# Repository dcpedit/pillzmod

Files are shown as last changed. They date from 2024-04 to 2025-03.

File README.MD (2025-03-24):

<p align="center">
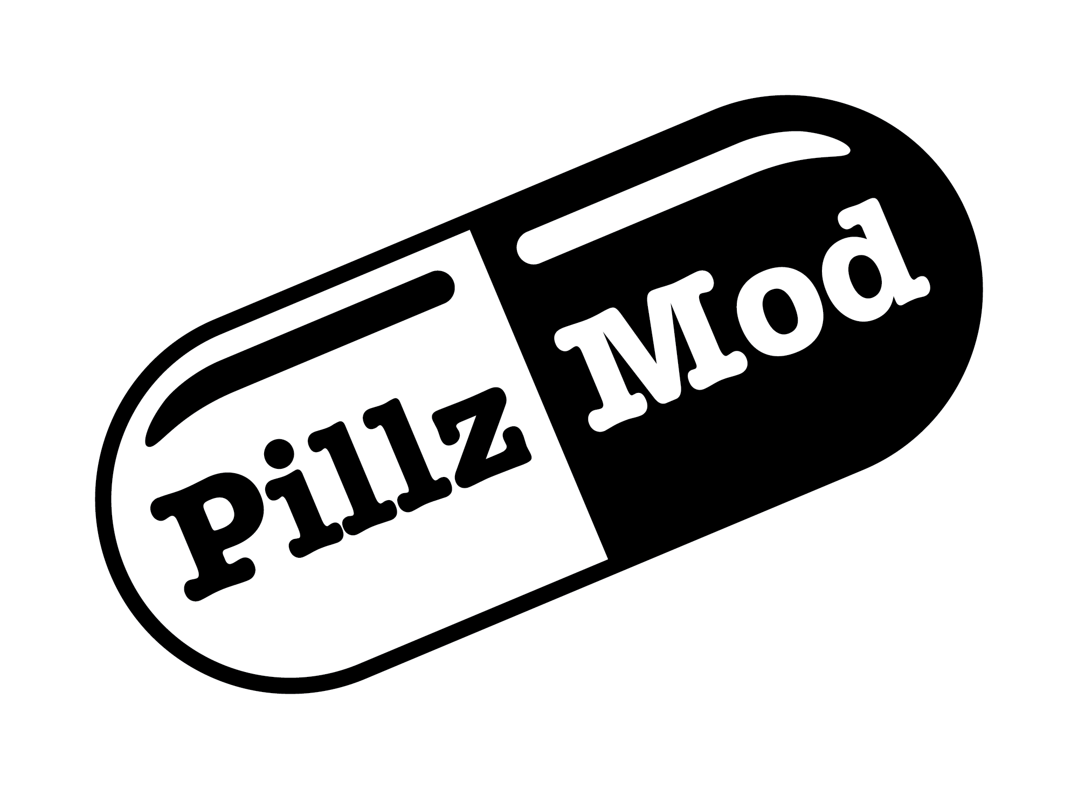
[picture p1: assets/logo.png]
  
</p>

# Pillz Mod for the Kinesis Advantage/Contoured

PCB
PillzMod

This project replaces my two previous forks ([kinesismod](https://github.com/dcpedit/kinesismod) and [kint](https://github.com/dcpedit/kint)) for adding Blackpill support to the Kinesis keyboard.  I've decided to merge all the features into a single PCB, add optional thumb cluster PCBs as part of the kit, and renamed the project to avoid confusion.  Below is a list of supported features.

* Supports Blackpill development board running QMK/Vial
* Supports Pill Bug wireless Bluetooth development board running ZMK
* Optional reversible thumb cluster PCB for left/right sides.  (Maintains original matrix wiring)
* 2u stabilizer support on thumb cluster

## "Pro" PCB Features

* Supports devlopment board with Pro-Micro footprint (Elite-C, Elite-Pi, Nice!Nano)
* Header for connecting up to 3 foot-pedals
* Piezo audio buzzer
* Header for extra data pin (Elite-C only)

## Attribution

Credit goes to the following people for doing all the initial development on replacment PCBs for the Kinesis:
 * Aaron Silman's [kinesismod project](https://gitlab.com/Silman/kinesismod.git) ([blog](https://silman.io/project/kinesis_mod/))
 * Michael Stapelberg's [KinT project](https://github.com/kinx-project/kint) ([blog](https://michael.stapelberg.ch/posts/2020-07-09-kint-kinesis-keyboard-controller/))
 * Dmitry Nosachev's [Kin80 project](https://github.com/DmNosachev/kin80)

## Ordering PCBs from JLCPCB

The files needed for https://jlcpcb.com are located in the production folders:
* Choose `pcb-pro/production` or `pcb/production` 
* `thumb-pcb/production`

Once uploaded, you place the order with the selected default options.  You can optionally change the solder mask color, which changes the final color of your PCB.

## Main PCB build guide
### Components
| Position | Description | Qty | Notes |
| --- | --- | --- | ----- |
| J1-J4 | Molex 39-53-2135 | 2 - 6  | [Link](https://octopart.com/39-53-2135-molex-7670149?r=sp)
| J3-J4 | Molex 39-53-2134 | 0 - 2  | Contoured only, [Link](https://octopart.com/search?q=Molex+39-53-2134)
| U1 | Header pins (1x20) | 2 | Should come with dev board
| U1 | Headers (1x20) | 2 | To socket your dev board
| D1-D4 | 1.8mm LED | 4 | [Amazon](https://a.co/d/90uynIs)
| R1-R4 | 10k resistor | 4 | Affects LED brightness. Smaller = brighter |
| | USB-C panel mount | 1 | [AliExpress](https://www.aliexpress.us/item/3256806463941289.html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), [Amazon](https://a.co/d/cRoqHqx)

### Blackpill Components
| Position | Description | Qty | Notes |
| --- | --- | --- | ----- |
| U1 | Blackpill (STM32F411) | 1 | [WeAct Store](https://www.aliexpress.com/store/1101545918?spm=a2g0o.order_list.order_list_main.2.18a31802pDYB6d)

#### -or- Pill Bug for wireless build

| Description | Qty | Notes |
| --- | --- | ----- |
| Pill Bug | 1 | [MechWild Store](https://mechwild.com/product/pillbug/)
| 3.7V battery | 1 | [2000mAh](https://a.co/d/dVUdHxi)
| Power button | 1 | Optional, [10mm](https://a.co/d/i33uBM0) or [19mm](https://a.co/d/fYN6ZX5)

### Additional "Pro" Components

| Position | Description | Qty | Notes |
| --- | --- | --- | ----- |
| U1 | Elite-C/Elite-Pi | 1 |
| | 3.7V battery | 1 | [2000mAh](https://a.co/d/dVUdHxi)
| U2 | 74HC595 | 1 | [Amazon](https://a.co/d/eLX9kOY)
| U2 | 16-pin IC socket | 1 | [Amazon](https://a.co/d/5EaFAHo)
| D6-D8 | 1n4148 Diode | 3 | [Link](https://www.mouser.com/ProductDetail/512-1N4148TR)
| BZ1 | Piezo Buzzer | 1 | [Link](https://www.digikey.com/en/products/detail/tdk-corporation/PS1240P02BT/935924)
| SW1 | Reset button | 1 | [Link](https://www2.mouser.com/ProductDetail/Alps-Alpine/SKQGAEE010?qs=N5Jky1br14PyTRvcw7F3eQ%3D%3D)
| R5-R19 | 10k Resistor | 15| AVR/Elite-C Only [Link](https://www.mouser.com/ProductDetail/YAGEO/MFR-12FTF52-10K?qs=oAGoVhmvjhzLlUYKKBtdYQ%3D%3D), [Link](https://mou.sr/3xgqcNf)

#### -or- Nice!Nano for wireless build

| Description | Qty | Notes |
| --- | --- | ----- |
| Nice!Nano | 1 | [Website](https://nicekeyboards.com/nice-nano/)
| 3.7V battery | 1 | [2000mAh](https://a.co/d/dVUdHxi)
| Power button | 1 | Optional, [10mm](https://a.co/d/i33uBM0) or [19mm](https://a.co/d/fYN6ZX5)

### Instructions



_NOTE: If you're using a battery that's larger than 500mAh, then bridge the charge boost jumper labeled JP1 with some solder.  This will increases the max charge rate from 100mA to 500mA. Doing this for small batteries (<500mAh) may cause explosions._

All components go on the side with the silkscreen labels (rectangles) EXCEPT for the LEDs.  First solder the header pins onto your development board, and the header sockets onto the PCB.  I prefer to use Mill-Max 310 series sockets because the pins are thin.  Then solder in the LED resistors, but NOT the actual LEDs yet.  The resistors can be SMD or through hole.

For a wireless build, you can now solder the battery wires/connector to the board.  Make sure the positive wire goes into "BAT+", and the negative wire goes into "BAT-".  If you're using a power button, make sure to wire it inline along the BAT+ wire so that it essentially opens and closes the circuit.

Insert your development board into the sockets on the PCB.

For the Molex connectors, I find that it's more convient to desolder the ones on the original PCB so that I don't have to purchase new ones.  Solder the connectors onto the PCB.

Flip the PCB over and insert the LEDs on the side of the PCB with no other components.  Make sure the short leg goes into the square pad, and bend the legs so that they stay in place.  Screw the PCB back into the keyboard case, making sure the LEDs are lined up with the existing case holes.  You can also adjust the height of the LED to move them closer to the status window if you'd like.  Once you're satisfied with the position of the LEDs, you can then solder them in place while the PCB is still mounted.

Lastly, plug the USB-C panel mount cable to into the development board, and secure the other end to the hole in the case.





### "Pro" Additional Instructions

The components required for this build and their position will depend on the development board you're using.  For example, pull-down resistors R5-R19 are only needed for AVR chips (Pro-Micro, Elite-C) since they don't support internal pull-downs for the row inputs.  Use the image below as a guide.



The Elite-C has an extra B0 pin that is broken out into the J10 pins.  You can use this to drive other components if you choose (ie. RGB strip, Solenoid)

* Pin 1 (square pad) - VCC
* Pin 2 - B0
* Pin 3 - GND

The J9 pins are for foot pedals and have the following assignment:

* Pin 1 (square pad) - Col6
* Pin 2 - Row0
* Pin 3 - Row1
* Pin 4 - Row2

Diodes D6-D8 are connected to the rows, so no additional diodes are needed in the pedals/switches.



### "Pro" Nice!Nano Additional Instructions

Mill-Max 310 sockets are recommended for socketing the Nice!Nano because thin pins are required for connecting the extra 3 pins in the middle.

The Nice!Nano is one pin short of supporting all 4 status lights on the Advantage.  If you want to utilize the unused numpad status LED as a power indicator, go ahead and short JP1 with some solder.



## Thumb cluster PCB build guide

The wiring for the thumb cluster (a.k.a. matrix wiring) has not been altered from original, so theoretically, they can be used in conjunction with any Kinesis PCB, including the stock one.

The PCB is also reversible, so you don't have to place separate orders for a "left" version and a "right" version.

### Components

| Description | Qty | Notes |
| --- | --- | ----- |
| 1N4148 SOD-123 diode | 12 | [Amazon](https://a.co/d/gsv8bGT)
| MX switch | 12 | Can desolder and reuse
| 2u screw-in stabilizer | 4 | [Link](https://divinikey.com/products/durock-v2-stabilizers-screw-in)
| Cable connector (1x10) | 4 | 2.54mm pitch (eg KF2510)
| Ribbon cable | 2 | >= 50mm length

### Instructions



You will need two PCBs for the thumb cluster, but since they're reversible, you will need to read the silkscreen to see if it's the left or right cluster.

First step is to solder all the 1N4148 diodes.  Orientation matters, so make sure the line on the diode faces same direction as the thicker white line on the PCB.  Place a dab of solder on ONE of the two diode pads.  Drop the diode into position (double checking the orientation), hold the diode in place with tweezers, and melt the solder you just added to the pad so that diode is held in place.  Now add solder to the opposite pad, thus holding the other diode leg in place.  Repeat for all the other diodes.

The connector for the ribbon cable can now be soldered onto the PCB, and will be on the same side as the diodes.  The pin pitch is 2.54mm, so any compatible connector/cable will work here.

Install the 2u stabilizers onto the PCB.

Now solder in your MX switches.  If you're reusing the original switches, desolder them from the original PCB, and remove the diode from inside the switch housing.  Using a switch opener will make this task much easier.



Mount the thumb clusters onto the keyboard and connect the ribbon cables.



## QMK firmware for "Pro"

* `firmware/pro_qmk_avr_default.bin`
* `firmware/pro_qmk_rp2040_default.uf2`

QMK source: https://github.com/dcpedit/qmk_firmware/tree/pillzmod/keyboards/dcpedit/pillzmod

## Vial firmware for Blackpill

* `firmware/blackpill_vial.bin`
* `firmware/dcpedit_kint_bp_vial_6layers.bin`

Source: https://github.com/dcpedit/vial-qmk/tree/pillzmod/keyboards/dcpedit/pillzmod

Remap keys: https://vial.rocks/

### Flashing firmware under Linux
The file firmware/dcpedit_kint_bp_vial_6layers.bin (or other) can simply be flashed to the Blackpill using the dfu-util. The dfu-util tool requires root privileges if settings are not accessible by the user.

Connect Blackpill to your Linux PC via USB C cable and start unit in DFU mode by holding bootp button and pressing reset button. Wait a second and release the bootp button.

Check the DFU devices by running
```
dfu-util -l
```
The Blackpill device should be visible.

Write the firmware to the device with
```
dfu-util -d 0483:df11 -a 0 -s 0x08000000 -D [PATH TO kint]/firmware/dcpedit_kint_bp_vial_6layers.bin
```

## Vial firmware for "Pro"

* `firmware/pro_vial_avr.hex`

Source: https://github.com/dcpedit/vial-qmk/tree/pillzmod/keyboards/dcpedit/pillzmod
(You will need to clone the entire branch since I had to make a core code change in `spi_master.c`)

## ZMK firmware for Pill Bug



* `firmware/zmk_default.uf2` - Default keymap
* `firmware/zmk_custom.uf2` - Support for up to 6 layers
* `firmware/zmk_reset.uf2` - Resets PillBug board for BT connectivity issue on MacOS      
* `firmware/zmk_studio.uf2` - Studio compatible (Progrm + Esc to unlock)

Source: https://github.com/dcpedit/zmk/tree/pillzmod/app/boards/shields/pillzmod

### Bluetooth with ZMK

The ZMK firmware has mappings for performing system tasks. By default there are 4 Bluetooth pairings saved to the keyboard but they do not switch automatically when adding new devices. So after you add the first device, you need to tell they keyboard to use Bluetooth slot 2 and so forth.
The keys to switch between are accessed by a different keyboard layer. This layer is opened by holding down the "Program" key at the very top right of the Kinesis and, while holding it, then clicking another key as follows:

* **Clear all saved Bluetooth profiles:** Program + F9
* **Bluetooth profile 1:** Program + F1
* **Bluetooth profile 2:** Program + F2
* **Bluetooth profile 3:** Program + F3
* **Bluetooth profile 4:** Program + F4
* **Enter bootloader mode (to upload UF2 files):** Program + - (the dash key just below program)

If you want to do a ZMK firmware build using GitHub actions, take a look at the following repository from keepitsimplejim:

https://github.com/keepitsimplejim/zmk-config-pillzmod-kinesis-adv

## ZMK firmware for "Pro" Nice!Nano

* `firmware/pro_zmk.uf2` - Default keymap
* `firmware/pro_zmk_studio.uf2` - Studio compatible (Progrm + Esc to unlock)

Source: https://github.com/dcpedit/zmk/tree/pillzmod/app/boards/shields/pillzmod_pro
Studio: https://zmk.studio/

## KiCad

All the PCBs were designed using KiCad, which is free and can be downloaded here: https://www.kicad.org/

For the thumb cluster PCB, I wasn't able to figure out how to have the left and right wiring co-exist without errors while sharing the same connector footprint.  My workaround was to first change the connector's reference designator to "J1", update the PCB from schematic, and wire up the left side.  Then I changed the reference designator to "J2", updated the PCB from schematic again, and wired up the right side.

If there are any KiCad experts out there that know of a more elegant solution, please let me know.

The production JLCPCB files are all generated with Fabrication Toolkit: https://github.com/bennymeg/Fabrication-Toolkit

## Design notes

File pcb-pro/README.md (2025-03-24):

# Pillz Mod Pro main PCB




Next image shows the mapping of keys to connectors and rows/columns:



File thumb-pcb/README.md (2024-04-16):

# Pillz Mod thumb cluster PCB



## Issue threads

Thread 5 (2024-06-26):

Documentation for flashing

epichub, 2024-06-26:
I am having a hard time figuring out how to flash the qmk .bin file - tried stm32cubeprogrammer, no luck. Trying with qmk compile now.
Would be nice with some docs on how to do it.

epichub, 2024-07-01:
got it to work via https://github.com/dcpedit/vial-qmk/tree/pillzmod/keyboards/dcpedit/pillzmod and
`make dcpedit/pillzmod/standard:default:flash`

but that image does not show up in vial/via - in macos i get "wrong version". maybe the jsons needs a small update?

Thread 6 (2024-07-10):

Blackpill STM32F411 not recognized

skamelone, 2024-07-10:
I'm having trouble flashing this board. Today, I received the **STM32F411** board and decided to check if I could flash it before soldering it onto the PCB. I can successfully flash it, but the board isn't recognized at all in VIA or Vial. I used the firmware [dcpedit_kint_bp_vial_6layers.bin](https://github.com/dcpedit/pillzmod/blob/main/firmware/dcpedit_kint_bp_vial_6layers.bin)

```
vial-qmk ➤ dfu-util --list
dfu-util 0.11

Copyright 2005-2009 Weston Schmidt, Harald Welte and OpenMoko Inc.
Copyright 2010-2021 Tormod Volden and Stefan Schmidt
This program is Free Software and has ABSOLUTELY NO WARRANTY
Please report bugs to http://sourceforge.net/p/dfu-util/tickets/

Found DFU: [0483:df11] ver=2200, devnum=1, cfg=1, intf=0, path="0-1", alt=3, name="@Device Feature/0xFFFF0000/01*004 e", serial="369A388B3233"
Found DFU: [0483:df11] ver=2200, devnum=1, cfg=1, intf=0, path="0-1", alt=2, name="@OTP Memory /0x1FFF7800/01*512 e,01*016 e", serial="369A388B3233"
Found DFU: [0483:df11] ver=2200, devnum=1, cfg=1, intf=0, path="0-1", alt=1, name="@Option Bytes  /0x1FFFC000/01*016 e", serial="369A388B3233"
Found DFU: [0483:df11] ver=2200, devnum=1, cfg=1, intf=0, path="0-1", alt=0, name="@Internal Flash  /0x08000000/04*016Kg,01*064Kg,03*128Kg", serial="369A388B3233"

vial-qmk ➤ dfu-util -vd 0483:df11 -a 0 -s 0x8000000 -D dcpedit_kint_bp_vial_6layers.bin
...
 Download from image offset 00010800 to memory 08010800-08010fff, size 2048
 Download from image offset 00011000 to memory 08011000-080117ff, size 2048
 Download from image offset 00011800 to memory 08011800-08011baf, size 944
File downloaded successfully
```

After reconnecting the board, I start VIA or VIAL and nothing. I also tried another STM32F411 and same thing. Any idea?

skamelone, 2024-07-10:
For anyone having the same error:

- If your board is **F411 8M HSE** (8Mhz) you need to add this to your keymap's rules.mk
```
BOARD = GENERIC_STM32_F411XE
MCU = STM32F411
```

- If your board is **F411 25M HSE** (25Mhz) you need to add this to your keymap's rules.mk
```
BOARD = BLACKPILL_STM32_F411
MCU = STM32F411
```

Closed 2024-07-10.

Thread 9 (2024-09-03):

Alternative for Pill Bug

Sinled, 2024-09-03:
It seems mechwild not accepting order anymore, so is there any alternatives for Pill Bug board, that will be wireless and run zmk?

a10kiloham, 2024-11-09:
the pro @dcpedit released is the answer now.

Closed 2024-11-09.

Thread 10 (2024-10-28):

QMK (Vial) source code pointing to wrong location

dhruvinsh, 2024-10-28:
Hi @dcpedit
As mentioned, the QMK firmware source code is missing. If you can point me to correct location that would be great. :)

dhruvinsh, 2024-10-29:
I think I found it, it was on different branch.
https://github.com/vial-kb/vial-qmk/compare/vial...dcpedit:vial-qmk:pillzmod

if that is the case, document (README.md) file need an update :)

dcpedit, 2024-10-30:
Thanks for pointing that out. Readme updated

Closed 2024-10-30.

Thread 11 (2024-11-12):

Proposal: usage of QH pin from Shift Registers for keypad led

dhruvinsh, 2024-11-12:
Hi.

Is it possible to connect keypad led to shift register pin `QH` ? if not how about moving one of the row to the Shift Register and connect keypad led to the controller?

dcpedit, 2025-01-16:
I considered this as well, but it won't work because the `Q` pins on the 74HC595 are input pins which are connected to the columns (output on MCU).  In order to drive the LED, I would need an output pin.  This is also why I can't use the shift register for row pins (row = input on MCU)

Closed 2025-01-16.

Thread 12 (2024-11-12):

Register Shifter connected on low frequency pin in case of Nice!Nano

dhruvinsh, 2024-11-12:
Register Shifter is connecto to the pin 13, 14 and 16. but in case of nice!nano those are low frequency pin. ZMK recommands to use high frequency pins which are highlighted in dark blue color.

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

HeavyDutySoul, 2024-11-12:
Anybody assemble on n!n? It work?

asmodeus812, 2024-12-28:
> Anybody assemble on n!n? It work?

@HeavyDutySoul have been using the nice nano v2 with the pro pcb version for a few weeks, seems to be working just fine,

dcpedit, 2025-01-16:
@dhruvinsh , thanks for pointing this out.  I chose those pins because they matched up with the SPI pins for the Pro Micro.  Do you know if using the low-freq pins have any adverse effects on the shift register functionality?  It seems to be working fine so far in my build.

dcpedit, 2025-03-24:
Thanks for finding this info. I’ll need to create a separate Nice!Nano-compatible PCB so I can reroute the traces to use the high-frequency pins. I can’t modify the existing PCB without breaking compatibility with the Pro Micro, whose SPI pins can’t be moved.

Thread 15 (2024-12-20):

[Nice Nano - ZMK] Keys on one side register themselves and keys on the other side

asmodeus812, 2024-12-20:
Hello, on the zmk nice nano firmware (latest) from this branch, the column of the 4,r,f,v, registers the keys of that column along side the column on the other side where the 6,y,h,n keys are, (note that the bottom most row works, and the arrow keys are registered correctly on the side they are pressed on) i can also see the same behavior on the thumb cluster where the delete key from the left side registers delete along side the page down on the right, and vice versa if you press page down on the right side it will also register the delete on the other side. I guess this is an issue with the shift register configuration possibly ?

asmodeus812, 2024-12-21:
That was a user error, during the soldering i seem to have used poor quality flux, which had completely covered the board in micro soldering droplets, which were almost impossible to notice, after a cleaning with alchohol the board works as expected, so does the default firmware as well. This is a word of caution for people which might encounter issues with the board while testing, make sure that there are no shorts anywhere.

Closed 2024-12-21.

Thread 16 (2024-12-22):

Do you have pro version of the pcb for sale?

cedounet, 2024-12-22:
Hello

I am not sure  where else to ask.. so using issue for that.

Bare pcb and maybe the hard to find connectors if needed, I am happy to buy them from you (I am in the UK).  If you don’t no issue either just close it.

thanks

ced
Ps: thanks a lot for this high quality work.

Closed 2025-01-03.

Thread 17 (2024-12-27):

Optional through-hole diodes on thumb PCB (feature request)

rwaldura, 2024-12-27:
Hello! Great project, super useful to bring back to life some older keyboards — my 1999 "Classic" thanks you!
I really appreciate how you provided the option to use either SMD or through-hole components for the main PCB, e.g. the LED resistors.
Would it be possible to achieve the same, with the thumb PCB? It appears only SMD is supported at this time.
I'd like to have the option to wire through-hole diodes, rather than SMD diodes, on the thumb PCB.
Thanks!

dcpedit, 2025-01-16:
This will not be difficult since the "left hand" diodes are wired differently than the "right hand" diodes.  In order to do this, I will need to use two diode footprints per key position, or simply just create 2 separate PCBs (one for left and another for right).

rwaldura, 2025-01-16:
I see. This had not occurred to me.
Thank you for looking into it!

rwaldura, 2025-03-24:
Sorry, the resolution here is that this feature will not be supported? Just want to know, thanks!

Closed 2025-03-24.

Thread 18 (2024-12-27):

Optional Molex connectors for thumb PCB (feature request)

rwaldura, 2024-12-27:
Recent Kinesis keyboards (Advantage2, KB600) use flat cables and Molex connectors to connect the main PCB to the thumbs. (Photo attached below.)
The current design requires a different kind of connector (which I don't have — I only got the Molex 39-53-2134 and 39-53-2135, prescribed for this build).
Looks like the main PCB already supports a Molex connector in this position? So this is my request to extend same to the thumb clusters.
Keep up the great work! Thanks!

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

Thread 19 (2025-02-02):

Triggering key and next in column on first rows

cedounet, 2025-02-02:
Hello,

I built the pro-version and used https://keeb.supply/products/0xcb-helios as a controller which is pin compatible to the pro... Everything works fine (on what I tested at least) but the first two rows.

I am using rows/col as per the schematics... so opposite of what it is physically on the keyboard

- Pressing one key on this row will systematically trigger the key _and_ the one below (next column)
   - _= _toggles _=_ and _tab_, tab toggle _tab_ and _capslock_
   - _1_ toggles _1_ and _q_ etc
   - It does that for those 3 first rows

- Same for the end key on thumb cluster that will also trigger a c after it (I reused the original thumb cluster)

I first thought this would be a soldering issue, but:
- I am having a hard time to see where a short would create this... would be all keys i.e. 1,q,a,z, not just the next one
- I have 2 keyboards... 2 controllers and both have the same issue on same rows...
- Using tweezers to activate the switch works flawlessly no triggering of next key.

Base are contour keyboards (PS2, and AT...) if that is relevant and I had some issues with them but not that one as far as i can remember and definitely not that systematic.

Any ideas on what could cause it or how I could debug that?

Thanks!

C

cedounet, 2025-02-05:
Looks like I need to use external pull down resistors… O had understood the RP2040 had internal ones but maybe they are not strong enough.  I only tried quickly but if confirmed I will close that issue…

Thanks

cedounet, 2025-02-22:
Works with pull down…

dcpedit, 2025-02-23:
This is interesting because I tested this with an Elite Pi which also uses an rp2040 and the internal pull downs were sufficient. Maybe I'll make a note of this in the readme.

cedounet, 2025-02-23:
Most key works… just those 2/3 rows.  As I said earlier I somewhat dismiss soldering issues as it happens on 4 combination of PcB and left key wells.

I could clearly see the 2 line going down briefly on the scope etc… and have half baked theories about why… but an extra pulldown sorted it.

I wanted to add the Helios or the readme but not sure if that is the reason it behaves differently from Elite-pi?

Closed 2025-02-22.

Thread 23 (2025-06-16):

zmk-pillzmod-pro does not compile?

epichub, 2025-06-16:
I cannot get you zmk-pillzmod-pro fork to compile.
It fails with some strange error originating from "leds.c" (a file which i cannot find in any other example of in any other board/shield in zmk):

```
[107/342] Building C object CMakeFiles/app.dir/boards/shields/pillzmod_pro/leds.c.obj
In file included from <MYBUILDDIR>/src/zmk-pillzmod/zephyr/include/zephyr/device.h:13,
                 from <MYBUILDDIR>/src/zmk-pillzmod/app/boards/shields/pillzmod_pro/leds.c:1:
<MYBUILDDIR>/src/zmk-pillzmod/zephyr/include/zephyr/init.h:193:44: warning: initialization of 'int (*)(void)' from incompatible pointer type 'int (*)(const struct device *)' [-Wincompatible-pointer-types]
  193 |                         .init_fn = {.sys = (init_fn_)},                        \
      |                                            ^
<MYBUILDDIR>/src/zmk-pillzmod/zephyr/include/zephyr/init.h:174:9: note: in expansion of macro 'SYS_INIT_NAMED'
  174 |         SYS_INIT_NAMED(init_fn, init_fn, level, prio)
      |         ^~~~~~~~~~~~~~
<MYBUILDDIR>/src/zmk-pillzmod/app/boards/shields/pillzmod_pro/leds.c:53:1: note: in expansion of macro 'SYS_INIT'
   53 | SYS_INIT(leds_init, APPLICATION, CONFIG_APPLICATION_INIT_PRIORITY);
      | ^~~~~~~~
<MYBUILDDIR>/src/zmk-pillzmod/zephyr/include/zephyr/init.h:193:44: note: (near initialization for '__init_leds_init.init_fn.sys')
  193 |                         .init_fn = {.sys = (init_fn_)},                        \
      |                                            ^
<MYBUILDDIR>/src/zmk-pillzmod/zephyr/include/zephyr/init.h:174:9: note: in expansion of macro 'SYS_INIT_NAMED'
  174 |         SYS_INIT_NAMED(init_fn, init_fn, level, prio)
      |         ^~~~~~~~~~~~~~
<MYBUILDDIR>/src/zmk-pillzmod/app/boards/shields/pillzmod_pro/leds.c:53:1: note: in expansion of macro 'SYS_INIT'
   53 | SYS_INIT(leds_init, APPLICATION, CONFIG_APPLICATION_INIT_PRIORITY);
      | ^~~~~~~~
[170/342] Building C object CMakeFiles/app.dir/src/studio/behavior_subsystem.c.obj
<MYBUILDDIR>/src/zmk-pillzmod/app/src/studio/behavior_subsystem.c: In function 'encode_value_description':
<MYBUILDDIR>/src/zmk-pillzmod/app/src/studio/behavior_subsystem.c:87:23: warning: assignment discards 'const' qualifier from pointer target type [-Wdiscarded-qualifiers]
   87 |         desc.name.arg = val;
      |                       ^
[175/342] Building C object CMakeFiles/app.dir/src/studio/uart_rpc_transport.c.obj
FAILED: CMakeFiles/app.dir/src/studio/uart_rpc_transport.c.obj
ccache /opt/zephyr-sdk/arm-zephyr-eabi/bin/arm-zephyr-eabi-gcc -DKERNEL -DNRF52840_XXAA -DPB_MAX_REQUIRED_FIELDS=64 -DPB_NO_ENCODE_SIZE_CHECK -DPB_NO_ERRMSG -DPB_WITHOUT_64BIT -DPICOLIBC_INTEGER_PRINTF_SCANF -D_FORTIFY_SOURCE=1 -D_POSIX_C_SOURCE=200809 -D__LINUX_ERRNO_EXTENSIONS__ -D__PROGRAM_START -D__ZEPHYR__=1 -I<MYBUILDDIR>/src/zmk-pillzmod/app/include -I<MYBUILDDIR>/src/zmk-pillzmod/app/build -I<MYBUILDDIR>/src/zmk-pillzmod/zephyr/include -I<MYBUILDDIR>/src/zmk-pillzmod/app/build/zephyr/include/generated -I<MYBUILDDIR>/src/zmk-pillzmod/zephyr/soc/arm/nordic_nrf/nrf52 -I<MYBUILDDIR>/src/zmk-pillzmod/zephyr/soc/arm/nordic_nrf/common/. -I<MYBUILDDIR>/src/zmk-pillzmod/zephyr/subsys/usb/device -I<MYBUILDDIR>/src/zmk-pillzmod/zephyr/subsys/bluetooth/controller/ll_sw/nordic/hal/nrf5/nrfx_glue -I<MYBUILDDIR>/src/zmk-pillzmod/zephyr/subsys/bluetooth -I<MYBUILDDIR>/src/zmk-pillzmod/zephyr/subsys/settings/include -I<MYBUILDDIR>/src/zmk-pillzmod/modules/lib/nanopb -I<MYBUILDDIR>/src/zmk-pillzmod/modules/hal/cmsis/CMSIS/Core/Include -I<MYBUILDDIR>/src/zmk-pillzmod/zephyr/modules/cmsis/. -I<MYBUILDDIR>/src/zmk-pillzmod/modules/hal/nordic/nrfx -I<MYBUILDDIR>/src/zmk-pillzmod/modules/hal/nordic/nrfx/drivers/include -I<MYBUILDDIR>/src/zmk-pillzmod/modules/hal/nordic/nrfx/mdk -I<MYBUILDDIR>/src/zmk-pillzmod/zephyr/modules/hal_nordic/nrfx/. -I<MYBUILDDIR>/src/zmk-pillzmod/modules/crypto/tinycrypt/lib/include -I<MYBUILDDIR>/src/zmk-pillzmod/app/module/include -I<MYBUILDDIR>/src/zmk-pillzmod/app/module/drivers/sensor/battery/. -fno-strict-aliasing -Os -imacros <MYBUILDDIR>/src/zmk-pillzmod/app/build/zephyr/include/generated/autoconf.h -fno-printf-return-value -fno-common -g -gdwarf-4 -fdiagnostics-color=always -mcpu=cortex-m4 -mthumb -mabi=aapcs -mfpu=fpv4-sp-d16 -mfloat-abi=hard -mfp16-format=ieee --sysroot=/opt/zephyr-sdk/arm-zephyr-eabi/arm-zephyr-eabi -imacros <MYBUILDDIR>/src/zmk-pillzmod/zephyr/include/zephyr/toolchain/zephyr_stdint.h -Wall -Wformat -Wformat-security -Wno-format-zero-length -Wno-pointer-sign -Wpointer-arith -Wexpansion-to-defined -Wno-unused-but-set-variable -Werror=implicit-int -fno-pic -fno-pie -fno-asynchronous-unwind-tables -ftls-model=local-exec -fno-reorder-functions --param=min-pagesize=0 -fno-defer-pop -fmacro-prefix-map=<MYBUILDDIR>/src/zmk-pillzmod/app=CMAKE_SOURCE_DIR -fmacro-prefix-map=<MYBUILDDIR>/src/zmk-pillzmod/zephyr=ZEPHYR_BASE -fmacro-prefix-map=<MYBUILDDIR>/src/zmk-pillzmod=WEST_TOPDIR -ffunction-sections -fdata-sections --specs=picolibc.specs -std=c99 -Wfatal-errors -MD -MT CMakeFiles/app.dir/src/studio/uart_rpc_transport.c.obj -MF CMakeFiles/app.dir/src/studio/uart_rpc_transport.c.obj.d -o CMakeFiles/app.dir/src/studio/uart_rpc_transport.c.obj -c <MYBUILDDIR>/src/zmk-pillzmod/app/src/studio/uart_rpc_transport.c
In file included from <MYBUILDDIR>/src/zmk-pillzmod/zephyr/include/zephyr/toolchain/gcc.h:98,
                 from <MYBUILDDIR>/src/zmk-pillzmod/zephyr/include/zephyr/toolchain.h:50,
                 from <MYBUILDDIR>/src/zmk-pillzmod/zephyr/include/zephyr/sys/util.h:18,
                 from <MYBUILDDIR>/src/zmk-pillzmod/zephyr/include/zephyr/init.h:13,
                 from <MYBUILDDIR>/src/zmk-pillzmod/app/src/studio/uart_rpc_transport.c:7:
<MYBUILDDIR>/src/zmk-pillzmod/zephyr/include/zephyr/device.h:85:41: error: '__device_dts_ord_DT_CHOSEN_zmk_studio_rpc_uart_ORD' undeclared here (not in a function)
   85 | #define DEVICE_NAME_GET(dev_id) _CONCAT(__device_, dev_id)
      |                                         ^~~~~~~~~
<MYBUILDDIR>/src/zmk-pillzmod/zephyr/include/zephyr/toolchain/common.h:137:26: note: in definition of macro '_DO_CONCAT'
  137 | #define _DO_CONCAT(x, y) x ## y
      |                          ^
<MYBUILDDIR>/src/zmk-pillzmod/zephyr/include/zephyr/device.h:85:33: note: in expansion of macro '_CONCAT'
   85 | #define DEVICE_NAME_GET(dev_id) _CONCAT(__device_, dev_id)
      |                                 ^~~~~~~
<MYBUILDDIR>/src/zmk-pillzmod/zephyr/include/zephyr/device.h:212:37: note: in expansion of macro 'DEVICE_NAME_GET'
  212 | #define DEVICE_DT_NAME_GET(node_id) DEVICE_NAME_GET(Z_DEVICE_DT_DEV_ID(node_id))
      |                                     ^~~~~~~~~~~~~~~
<MYBUILDDIR>/src/zmk-pillzmod/zephyr/include/zephyr/device.h:229:34: note: in expansion of macro 'DEVICE_DT_NAME_GET'
  229 | #define DEVICE_DT_GET(node_id) (&DEVICE_DT_NAME_GET(node_id))
      |                                  ^~~~~~~~~~~~~~~~~~
<MYBUILDDIR>/src/zmk-pillzmod/app/src/studio/uart_rpc_transport.c:21:46: note: in expansion of macro 'DEVICE_DT_GET'
   21 | static const struct device *const uart_dev = DEVICE_DT_GET(UART_DEVICE_NODE);
      |                                              ^~~~~~~~~~~~~
compilation terminated due to -Wfatal-errors.
[181/342] Building C object CMakeFiles/app.dir/src/studio/keymap_subsystem.c.obj
<MYBUILDDIR>/src/zmk-pillzmod/app/src/studio/keymap_subsystem.c: In function 'encode_layouts':
<MYBUILDDIR>/src/zmk-pillzmod/app/src/studio/keymap_subsystem.c:304:25: warning: assignment discards 'const' qualifier from pointer target type [-Wdiscarded-qualifiers]
  304 |         layout.name.arg = l;
      |                         ^
<MYBUILDDIR>/src/zmk-pillzmod/app/src/studio/keymap_subsystem.c:307:25: warning: assignment discards 'const' qualifier from pointer target type [-Wdiscarded-qualifiers]
  307 |         layout.keys.arg = l;
      |                         ^
<MYBUILDDIR>/src/zmk-pillzmod/app/src/studio/keymap_subsystem.c: In function 'restore_layer':
<MYBUILDDIR>/src/zmk-pillzmod/app/src/studio/keymap_subsystem.c:462:33: warning: assignment discards 'const' qualifier from pointer target type [-Wdiscarded-qualifiers]
  462 |         resp.result.ok.name.arg = &restore_req->layer_id;
      |                                 ^
<MYBUILDDIR>/src/zmk-pillzmod/app/src/studio/keymap_subsystem.c:465:37: warning: assignment discards 'const' qualifier from pointer target type [-Wdiscarded-qualifiers]
  465 |         resp.result.ok.bindings.arg = &restore_req->layer_id;
      |                                     ^
[192/342] Building C object zephyr/subsys/bluetooth/host/CMakeFiles/subsys__bluetooth__host.dir/hci_core.c.obj
ninja: build stopped: subcommand failed.

```

I am guessing some update in zephyr/zmk broke how you zmk-pillzmod_pro is interfacing with the rest of zmk/zephyr?

epichub, 2025-06-29:
I made a modernized(?) refactor of your code - that builds on via github actions (it will get you fresh uf2 files!).
you can find the firmware/conf here:
- https://github.com/epichub/pillzmodpro-zmk-firmware
- the module it relies on (where 90% of your code now lives): https://github.com/epichub/pillzmodpro-zmk-module

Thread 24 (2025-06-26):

Soft off and wakup zmk behavior

asmodeus812, 2025-06-26:
I have been trying to achieve the soft_off and wakeup feature with the firmware, however while i can trigger the keyboard to go into deep sleep with soft_off behavior i am unable to configure any of the keyboard keys to force the keyboard to wake up from deep sleep, is that even possible to do with the current wiring ? I wanted to configure certain keys on the Function row to wake up the keyboard when pressed. AT the moment the only way to force it to wake up is to plug it in to a power source or the pc, but that is not ideal.

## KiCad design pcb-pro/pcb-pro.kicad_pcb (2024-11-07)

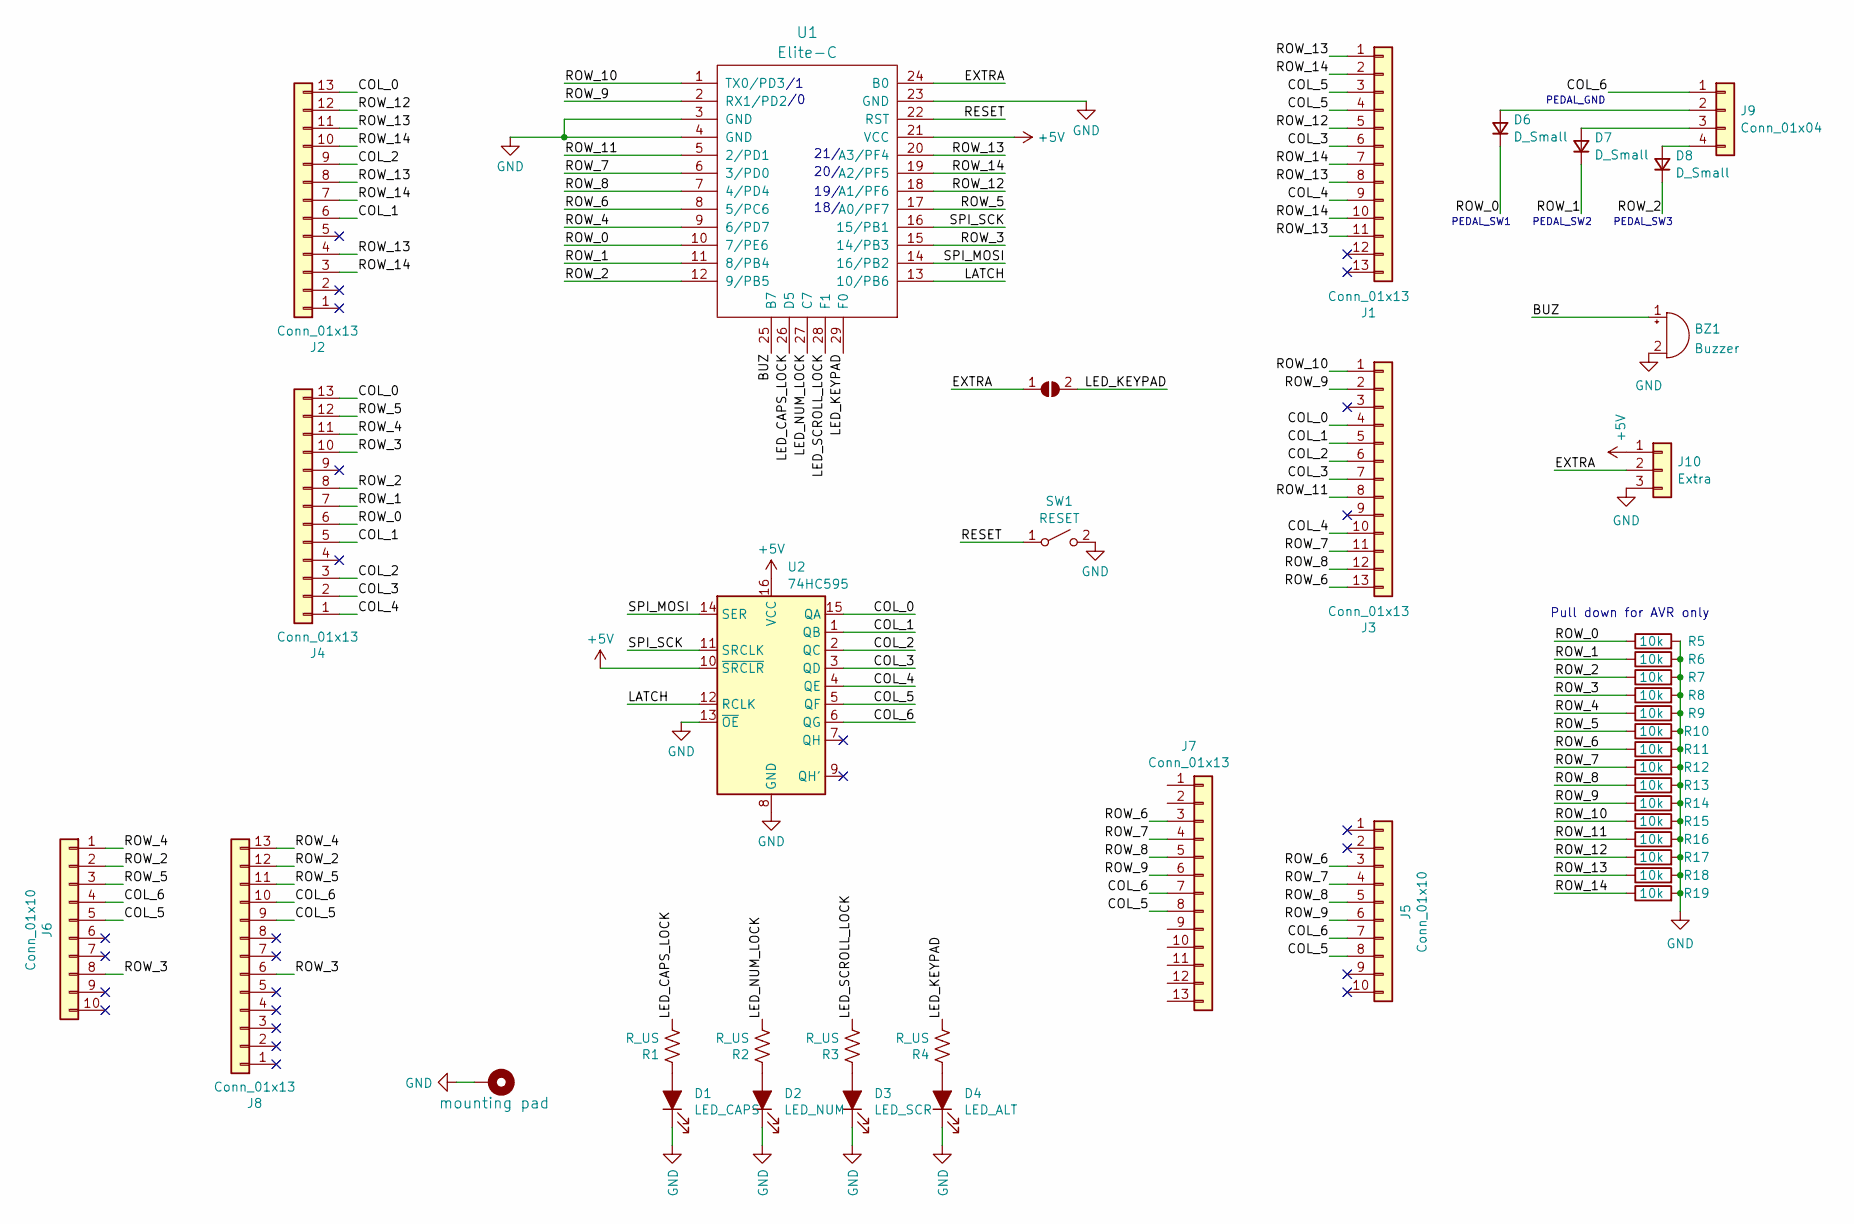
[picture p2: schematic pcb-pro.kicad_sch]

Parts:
BZ1: Buzzer
D1: LED_CAPS; LED_D3.0mm
D2: LED_NUM; LED_D3.0mm
D3: LED_SCR; LED_D3.0mm
D4: LED_ALT; LED_D3.0mm
D6, D7, D8: D_Small
H1: mounting pad; MountingHole_4.3mm_M4_Pad
J1, J2, J7, J8: Conn_01x13; Molex_0039532135
J3, J4: Conn_01x13; Molex_039532134
J5, J6: Conn_01x10; Pin_Header_Straight_1x10_Pitch2.54mm
J9: Conn_01x04
J10: Extra
JP1: SolderJumper_2_Open; SolderJumper-2_P1.3mm_Open_RoundedPad1.0x1.5mm
R1, R2, R3, R4: R_US; R_Axial_DIN0204_L3.6mm_D1.6mm_P5.08mm_Horizontal
R5, R6, R7, R8, R9, R10, R11, R12, R13, R14, R15, R16, R17, R18, R19: 10k
SW1: RESET
U1: Elite-C
U2: 74HC595

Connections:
+5V: J10.1, U1.21 (VCC), U2.10 (~SRCLR), U2.16 (VCC)
/BUZ: BZ1.1 (-), U1.25 (B7)
/COL_0: J2.13, J3.4, J4.13, U2.15 (QA)
/COL_1: J2.6, J3.5, J4.5, U2.1 (QB)
/COL_2: J2.9, J3.6, J4.3, U2.2 (QC)
/COL_3: J1.6, J3.7, J4.2, U2.3 (QD)
/COL_4: J1.9, J3.10, J4.1, U2.4 (QE)
/COL_5: J1.3, J1.4, J5.8, J6.5, J7.8, J8.9, U2.5 (QF)
/COL_6: J5.7, J6.4, J7.7, J8.10, J9.1, U2.6 (QG)
/EXTRA: J10.2, JP1.1 (A), U1.24 (B0)
/LATCH: U1.13 (10/PB6), U2.12 (RCLK)
/LED_CAPS_LOCK: R1.2, U1.26 (D5)
/LED_KEYPAD: JP1.2 (B), R4.2, U1.29 (F0)
/LED_NUM_LOCK: R2.2, U1.27 (C7)
/LED_SCROLL_LOCK: R3.2, U1.28 (F1)
/RESET: SW1.1 (A), U1.22 (RST)
/ROW_0: D6.1 (K), J4.6, R5.1, U1.10 (7/PE6)
/ROW_1: D7.1 (K), J4.7, R6.1, U1.11 (8/PB4)
/ROW_2: D8.1 (K), J4.8, J6.2, J8.12, R7.1, U1.12 (9/PB5)
/ROW_3: J4.10, J6.8, J8.6, R8.1, U1.15 (14/PB3)
/ROW_4: J4.11, J6.1, J8.13, R9.1, U1.9 (6/PD7)
/ROW_5: J4.12, J6.3, J8.11, R10.1, U1.17 (A0/PF7)
/ROW_6: J3.13, J5.3, J7.3, R11.1, U1.8 (5/PC6)
/ROW_7: J3.11, J5.4, J7.4, R12.1, U1.6 (3/PD0)
/ROW_8: J3.12, J5.5, J7.5, R13.1, U1.7 (4/PD4)
/ROW_9: J3.2, J5.6, J7.6, R14.1, U1.2 (RX1/PD2)
/ROW_10: J3.1, R15.1, U1.1 (TX0/PD3)
/ROW_11: J3.8, R16.1, U1.5 (2/PD1)
/ROW_12: J1.5, J2.12, R17.1, U1.18 (A1/PF6)
/ROW_13: J1.1, J1.8, J1.11, J2.4, J2.8, J2.11, R18.1, U1.20 (A3/PF4)
/ROW_14: J1.2, J1.7, J1.10, J2.3, J2.7, J2.10, R19.1, U1.19 (A2/PF5)
/SPI_MOSI: U1.14 (16/PB2), U2.14 (SER)
/SPI_SCK: U1.16 (15/PB1), U2.11 (SRCLK)
GND: BZ1.2 (+), D1.1 (K), D2.1 (K), D3.1 (K), D4.1 (K), H1.1, J10.3, R5.2, R6.2, R7.2, R8.2, R9.2, R10.2, R11.2, R12.2, R13.2, R14.2, R15.2, R16.2, R17.2, R18.2, R19.2, SW1.2 (B), U1.3 (GND), U1.4 (GND), U1.23 (GND), U2.8 (GND), U2.13 (~OE)
unnamed: D1.2 (A), R1.1
unnamed: D2.2 (A), R2.1
unnamed: D3.2 (A), R3.1
unnamed: D4.2 (A), R4.1
unnamed: D6.2 (A), J9.2
unnamed: D7.2 (A), J9.3
unnamed: D8.2 (A), J9.4

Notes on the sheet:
Pull down for AVR only
18/
PEDAL_SW3
19/
20/
PEDAL_SW1
21/
PEDAL_GND
PEDAL_SW2

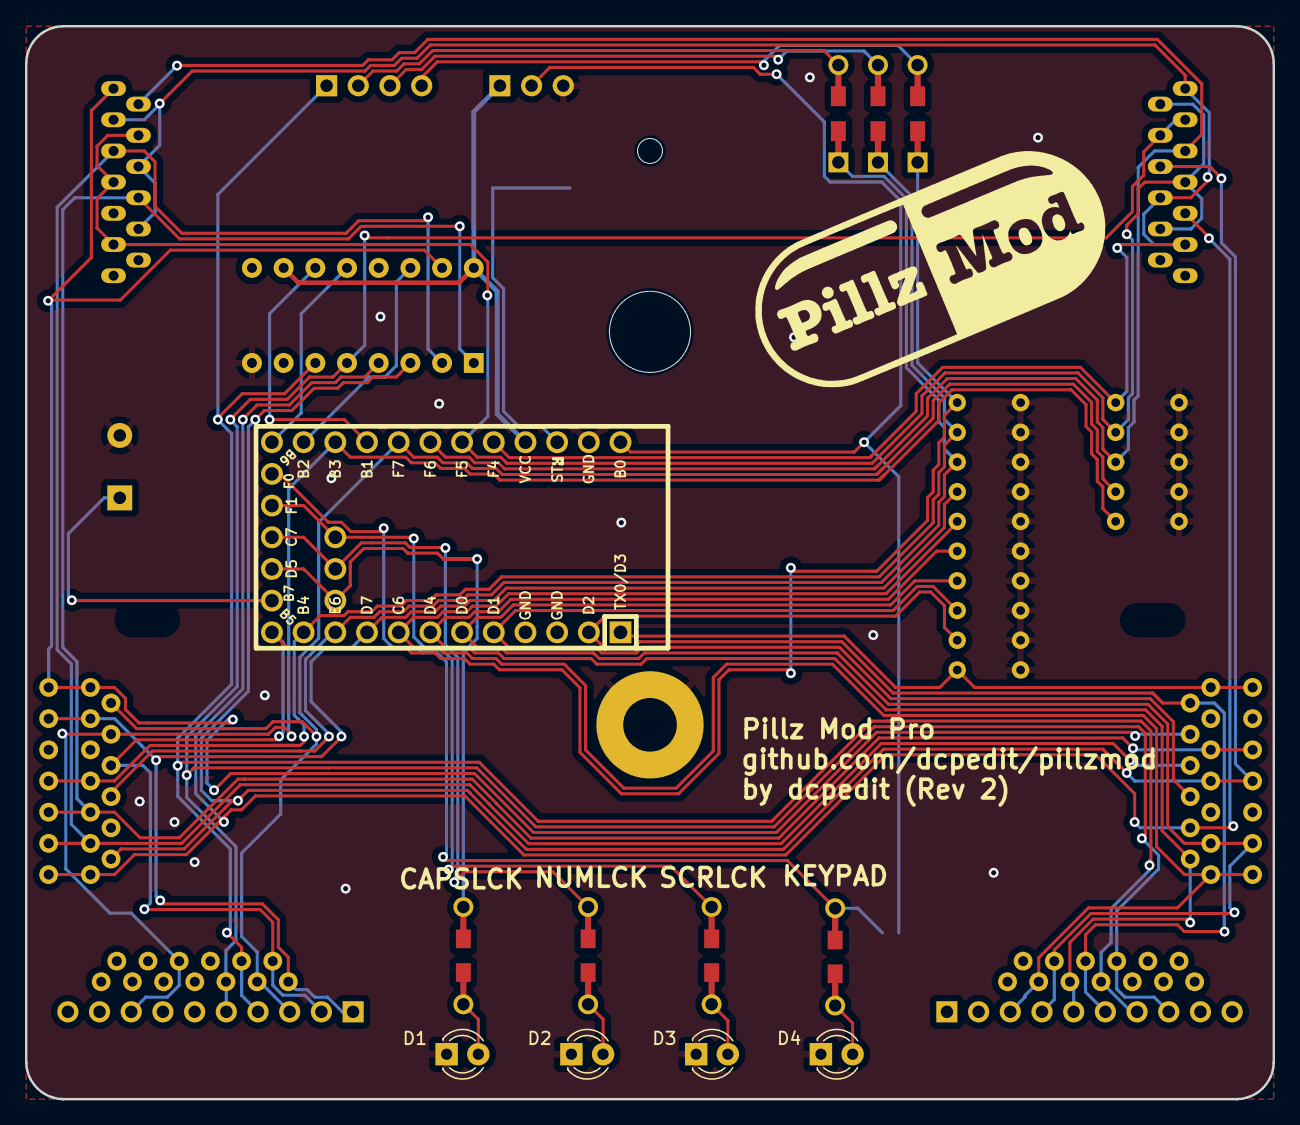
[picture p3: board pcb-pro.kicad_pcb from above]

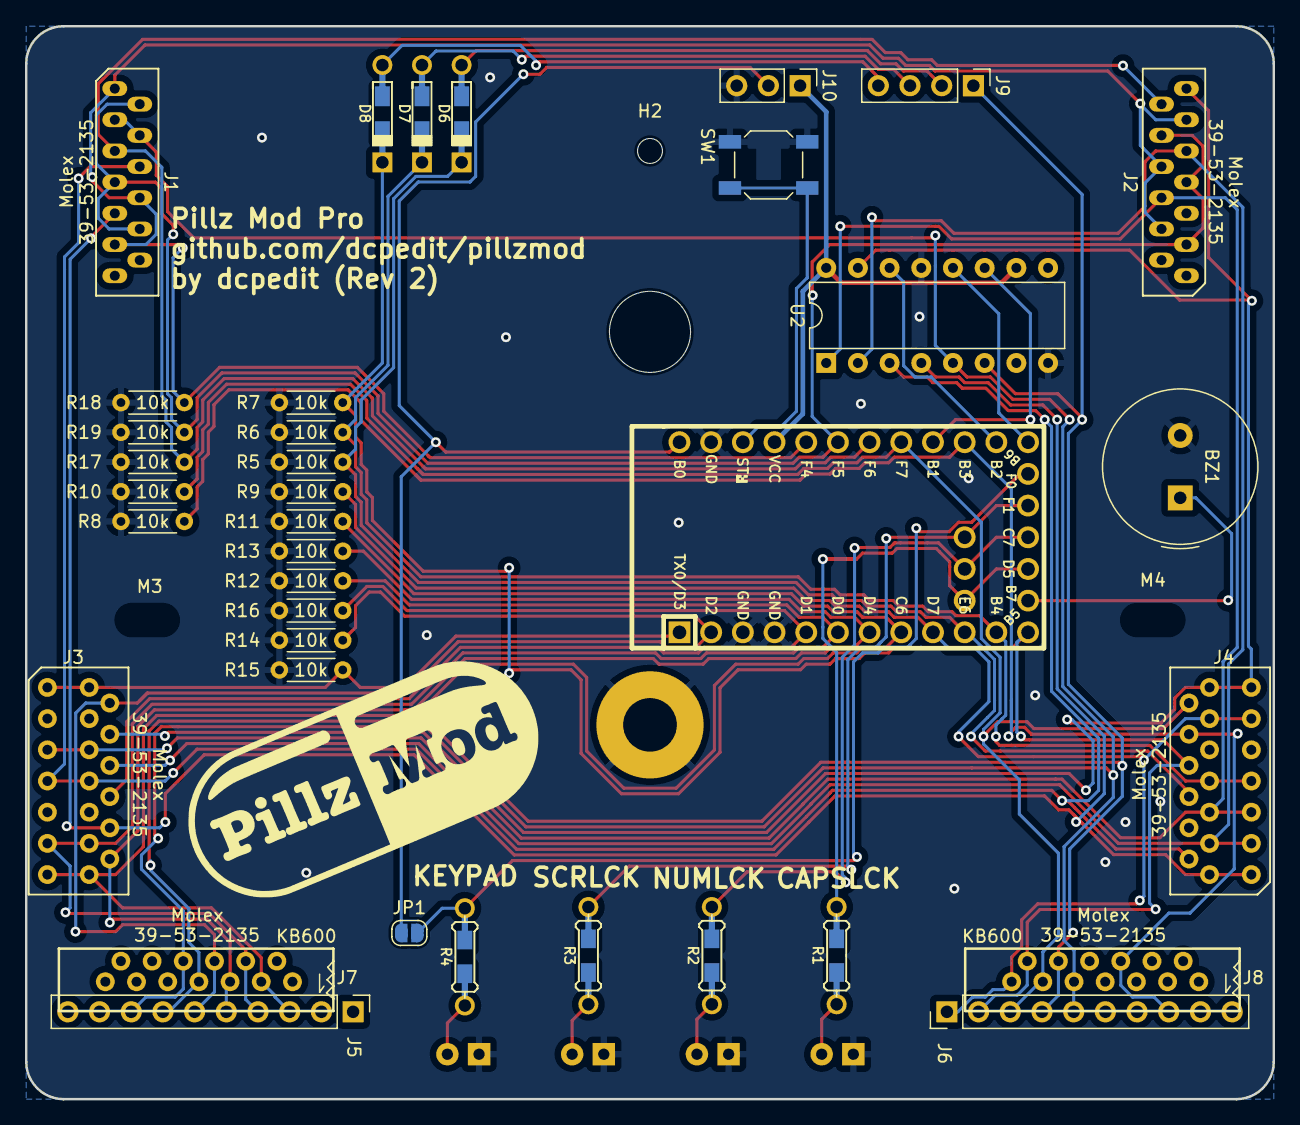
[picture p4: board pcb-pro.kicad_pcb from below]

Board: 2 copper layers, 100.0 x 86.0 mm, 46 parts (41 on the bottom side), 41 nets.

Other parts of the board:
H2: mounting pad; MountingHole_2mm
M1: MountingHole_6.4mm_M6
M3, M4: MountingHole_4.3mm_M4

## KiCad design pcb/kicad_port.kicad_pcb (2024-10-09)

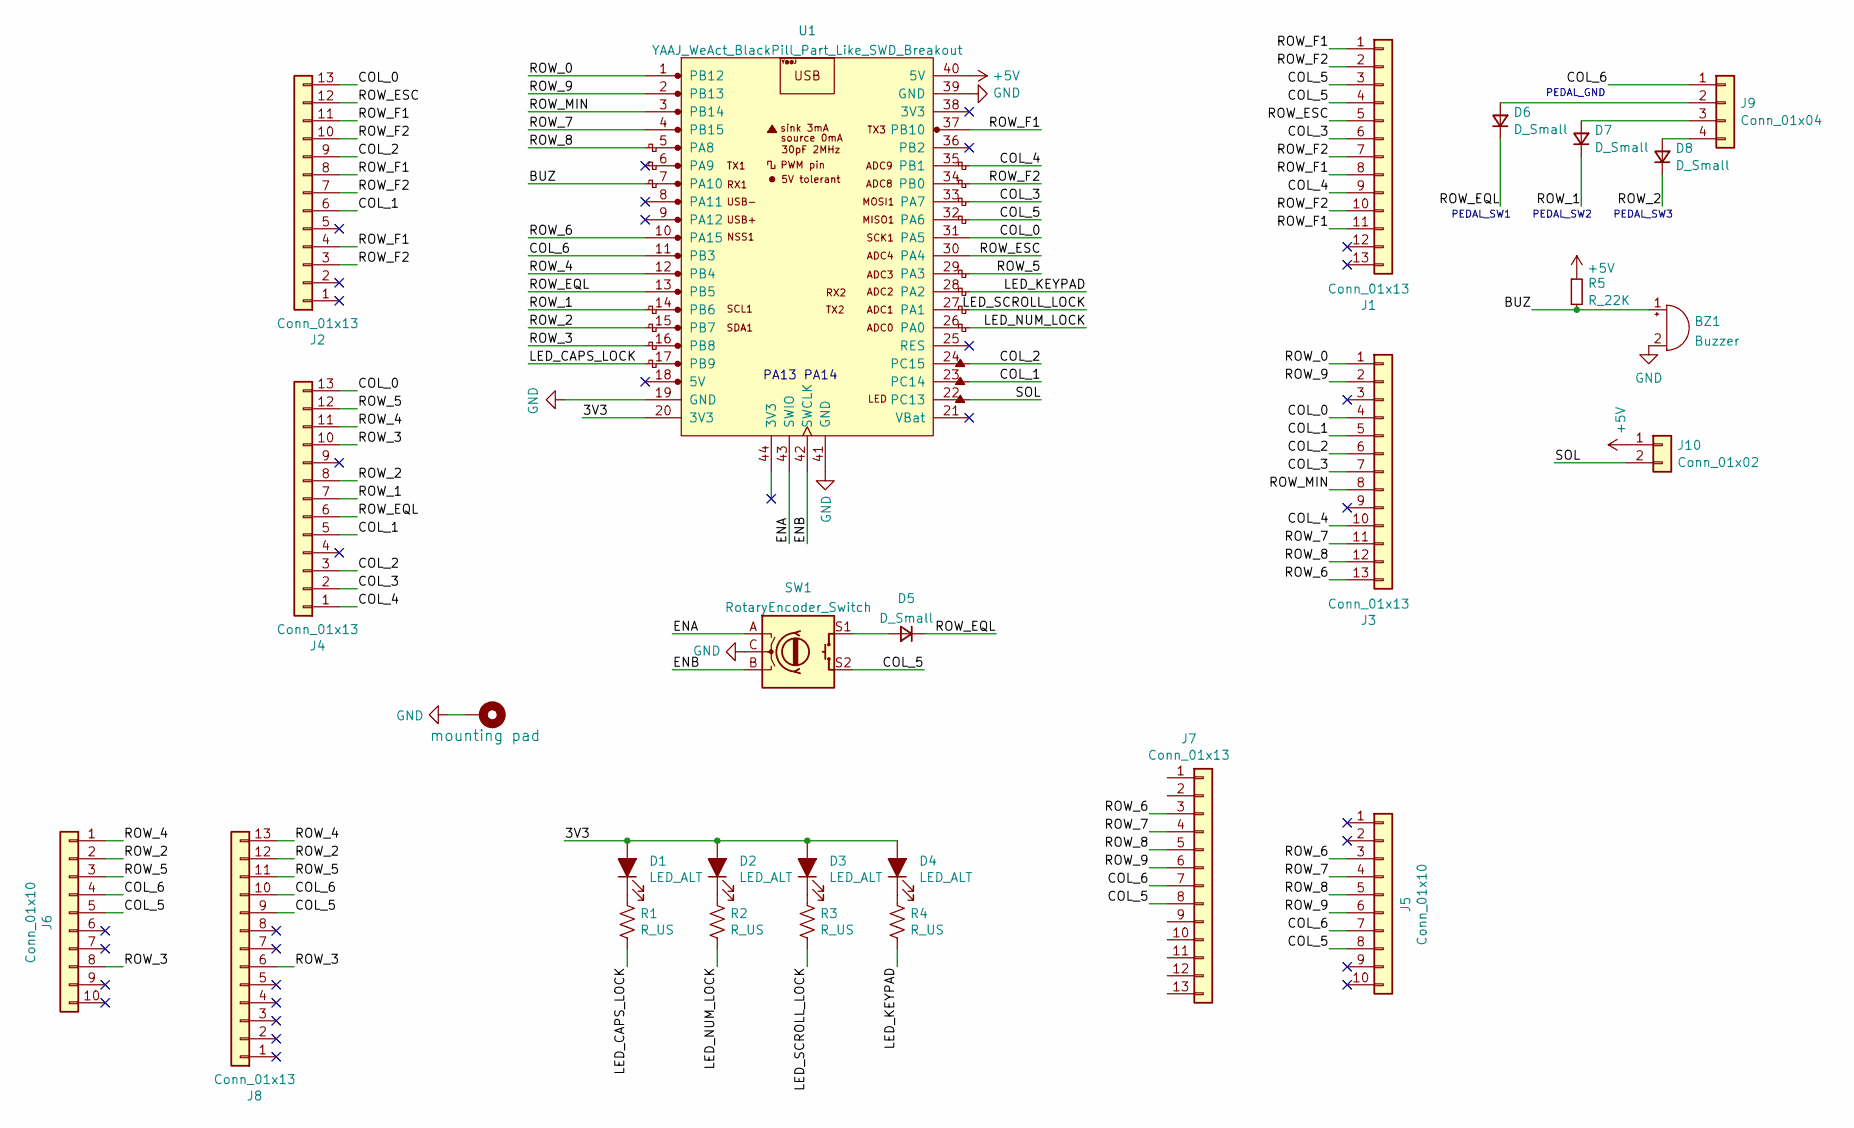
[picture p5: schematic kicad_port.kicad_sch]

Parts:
BZ1: Buzzer
D1, D2, D3, D4: LED_ALT; LED_D3.0mm
D5, D6, D7, D8: D_Small
H1: mounting pad; MountingHole_4.3mm_M4_Pad
J1, J2, J7, J8: Conn_01x13; Molex_0039532135
J3, J4: Conn_01x13; Molex_039532134
J5, J6: Conn_01x10; Pin_Header_Straight_1x10_Pitch2.54mm
J9: Conn_01x04
J10: Conn_01x02
R1, R2, R3, R4: R_US; R_Axial_DIN0204_L3.6mm_D1.6mm_P5.08mm_Horizontal
R5: R_22K; Resistor
SW1: RotaryEncoder_Switch
U1: YAAJ_WeAct_BlackPill_Part_Like_SWD_Breakout; YAAJ_WeAct_BlackPill_SWD_2

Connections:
+5V: J10.1, R5.1, U1.40 (5V)
/3V3: D1.2 (A), D2.2 (A), D3.2 (A), D4.2 (A), U1.20 (3V3)
/BUZ: BZ1.1 (-), R5.2, U1.7 (PA10)
/COL_0: J2.13, J3.4, J4.13, U1.31 (PA5)
/COL_1: J2.6, J3.5, J4.5, U1.23 (PC14)
/COL_2: J2.9, J3.6, J4.3, U1.24 (PC15)
/COL_3: J1.6, J3.7, J4.2, U1.33 (PA7)
/COL_4: J1.9, J3.10, J4.1, U1.35 (PB1)
/COL_5: J1.3, J1.4, J5.8, J6.5, J7.8, J8.9, SW1.S2, U1.32 (PA6)
/COL_6: J5.7, J6.4, J7.7, J8.10, J9.1, U1.11 (PB3)
/ENA: SW1.A, U1.43 (SWIO)
/ENB: SW1.B, U1.42 (SWCLK)
/LED_CAPS_LOCK: R1.2, U1.17 (PB9)
/LED_KEYPAD: R4.2, U1.28 (PA2)
/LED_NUM_LOCK: R2.2, U1.26 (PA0)
/LED_SCROLL_LOCK: R3.2, U1.27 (PA1)
/ROW_0: J3.1, U1.1 (PB12)
/ROW_1: D7.1 (K), J4.7, U1.14 (PB6)
/ROW_2: D8.1 (K), J4.8, J6.2, J8.12, U1.15 (PB7)
/ROW_3: J4.10, J6.8, J8.6, U1.16 (PB8)
/ROW_4: J4.11, J6.1, J8.13, U1.12 (PB4)
/ROW_5: J4.12, J6.3, J8.11, U1.29 (PA3)
/ROW_6: J3.13, J5.3, J7.3, U1.10 (PA15)
/ROW_7: J3.11, J5.4, J7.4, U1.4 (PB15)
/ROW_8: J3.12, J5.5, J7.5, U1.5 (PA8)
/ROW_9: J3.2, J5.6, J7.6, U1.2 (PB13)
/ROW_EQL: D5.1 (K), D6.1 (K), J4.6, U1.13 (PB5)
/ROW_ESC: J1.5, J2.12, U1.30 (PA4)
/ROW_F1: J1.1, J1.8, J1.11, J2.4, J2.8, J2.11, U1.37 (PB10)
/ROW_F2: J1.2, J1.7, J1.10, J2.3, J2.7, J2.10, U1.34 (PB0)
/ROW_MIN: J3.8, U1.3 (PB14)
/SOL: J10.2, U1.22 (PC13)
GND: BZ1.2 (+), H1.1, SW1.C, U1.19 (GND), U1.39 (GND), U1.41 (GND)
unnamed: D1.1 (K), R1.1
unnamed: D2.1 (K), R2.1
unnamed: D3.1 (K), R3.1
unnamed: D4.1 (K), R4.1
unnamed: D5.2 (A), SW1.S1
unnamed: D6.2 (A), J9.2
unnamed: D7.2 (A), J9.3
unnamed: D8.2 (A), J9.4

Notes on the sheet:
PA13 PA14
PEDAL_SW3
PEDAL_SW1
PEDAL_GND
PEDAL_SW2

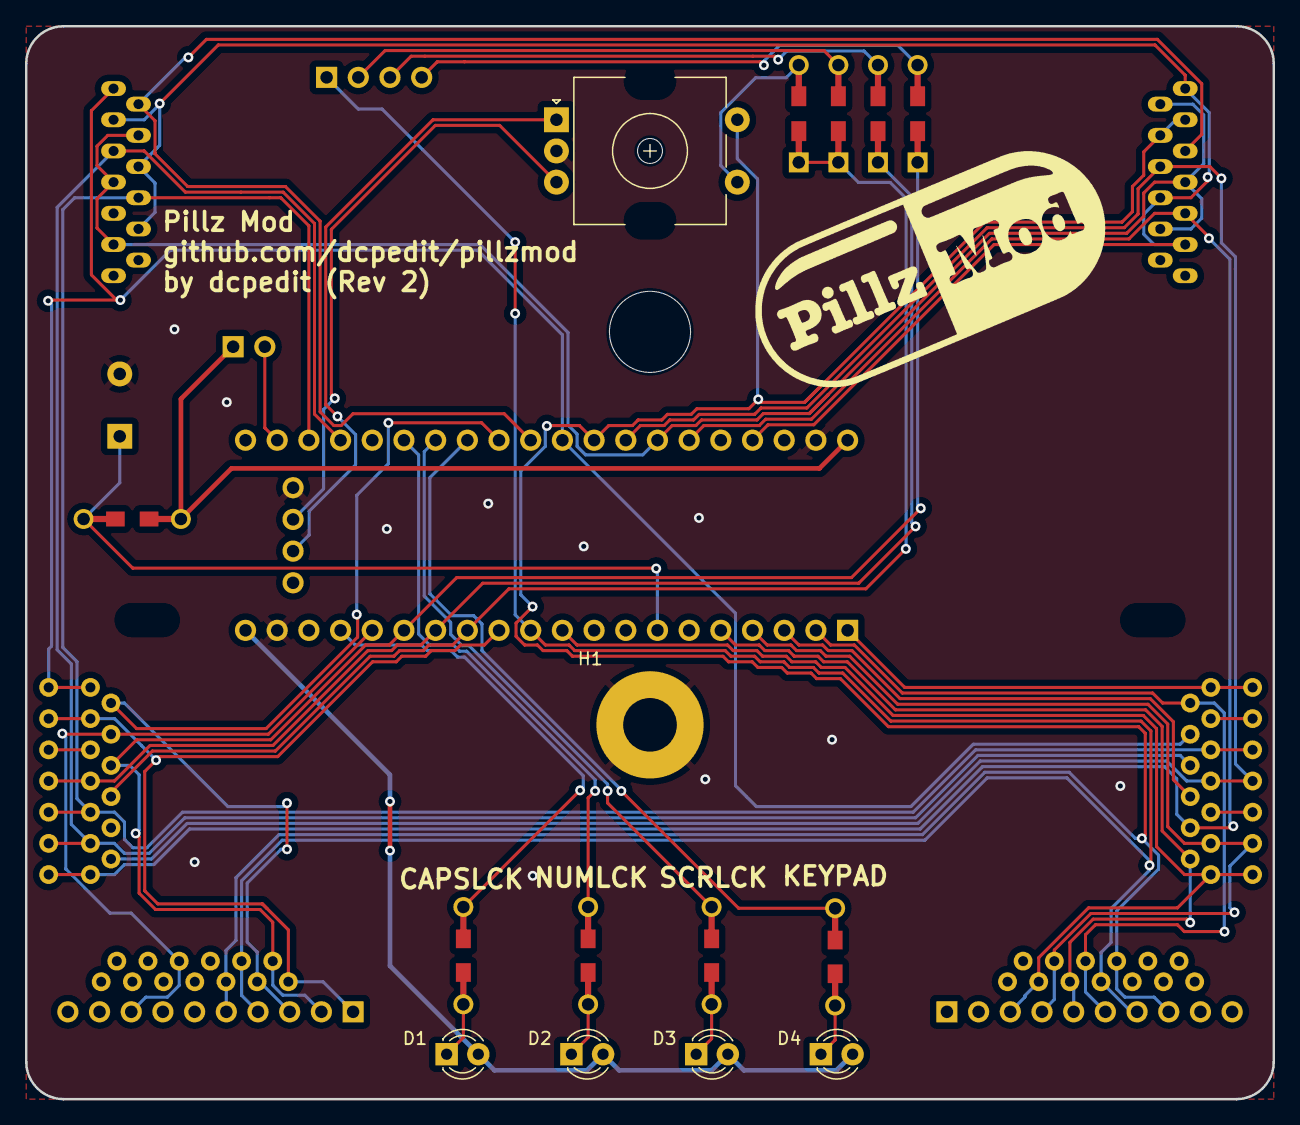
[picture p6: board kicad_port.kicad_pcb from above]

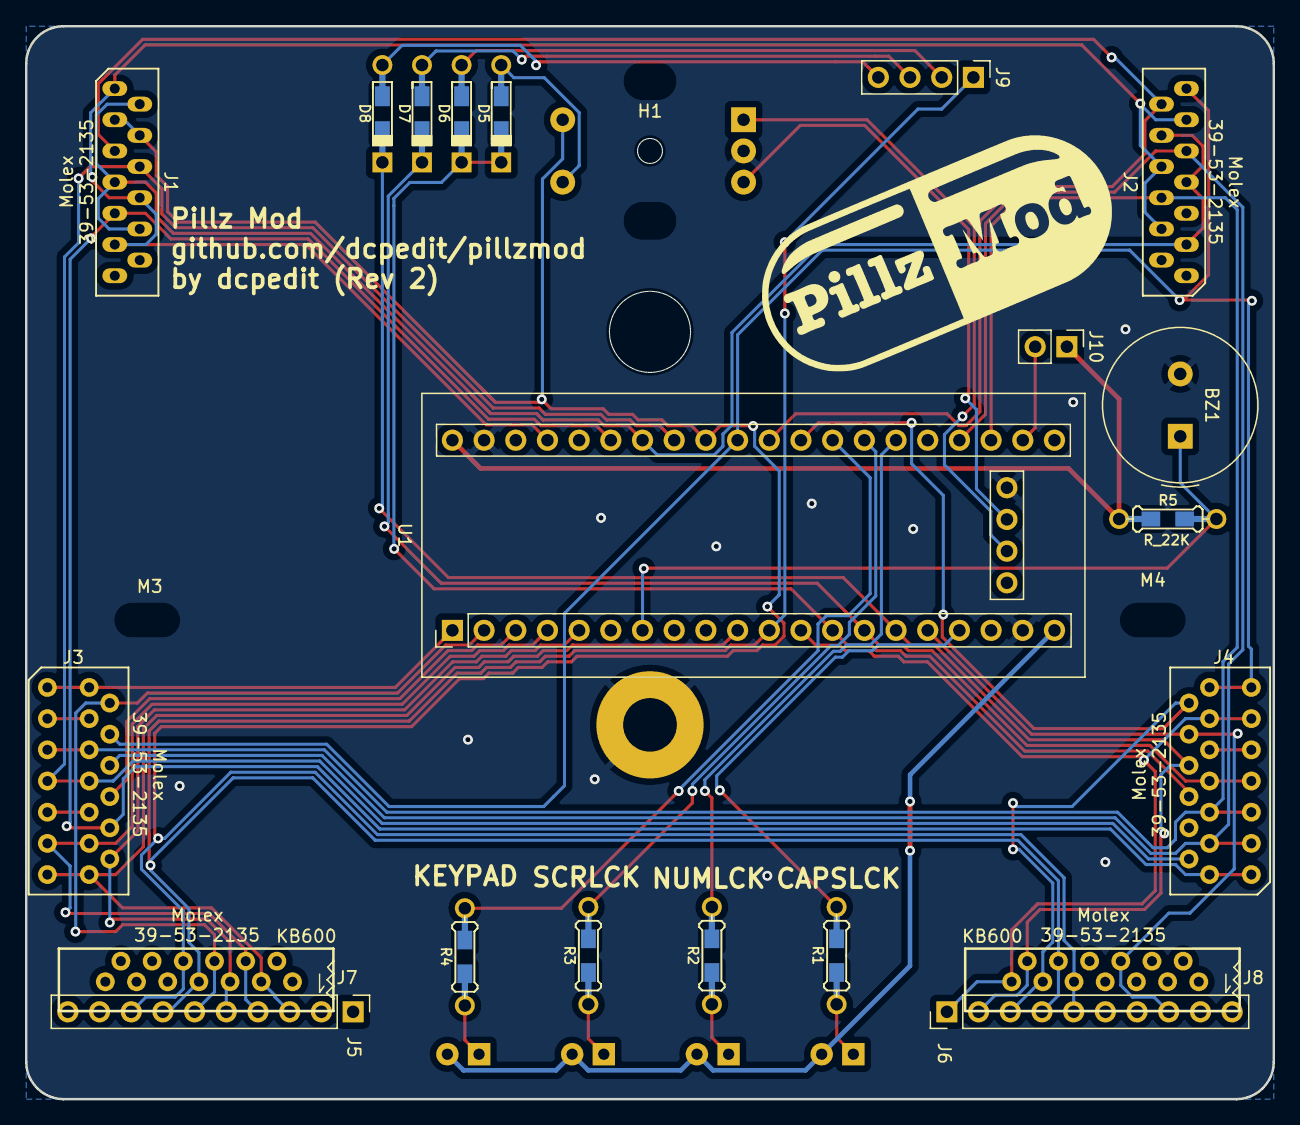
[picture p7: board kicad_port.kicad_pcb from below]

Board: 2 copper layers, 100.0 x 86.0 mm, 31 parts (25 on the bottom side), 41 nets.

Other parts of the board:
H1#2: mounting pad; MountingHole_2mm
M1: MountingHole_6.4mm_M6
M3, M4: MountingHole_4.3mm_M4

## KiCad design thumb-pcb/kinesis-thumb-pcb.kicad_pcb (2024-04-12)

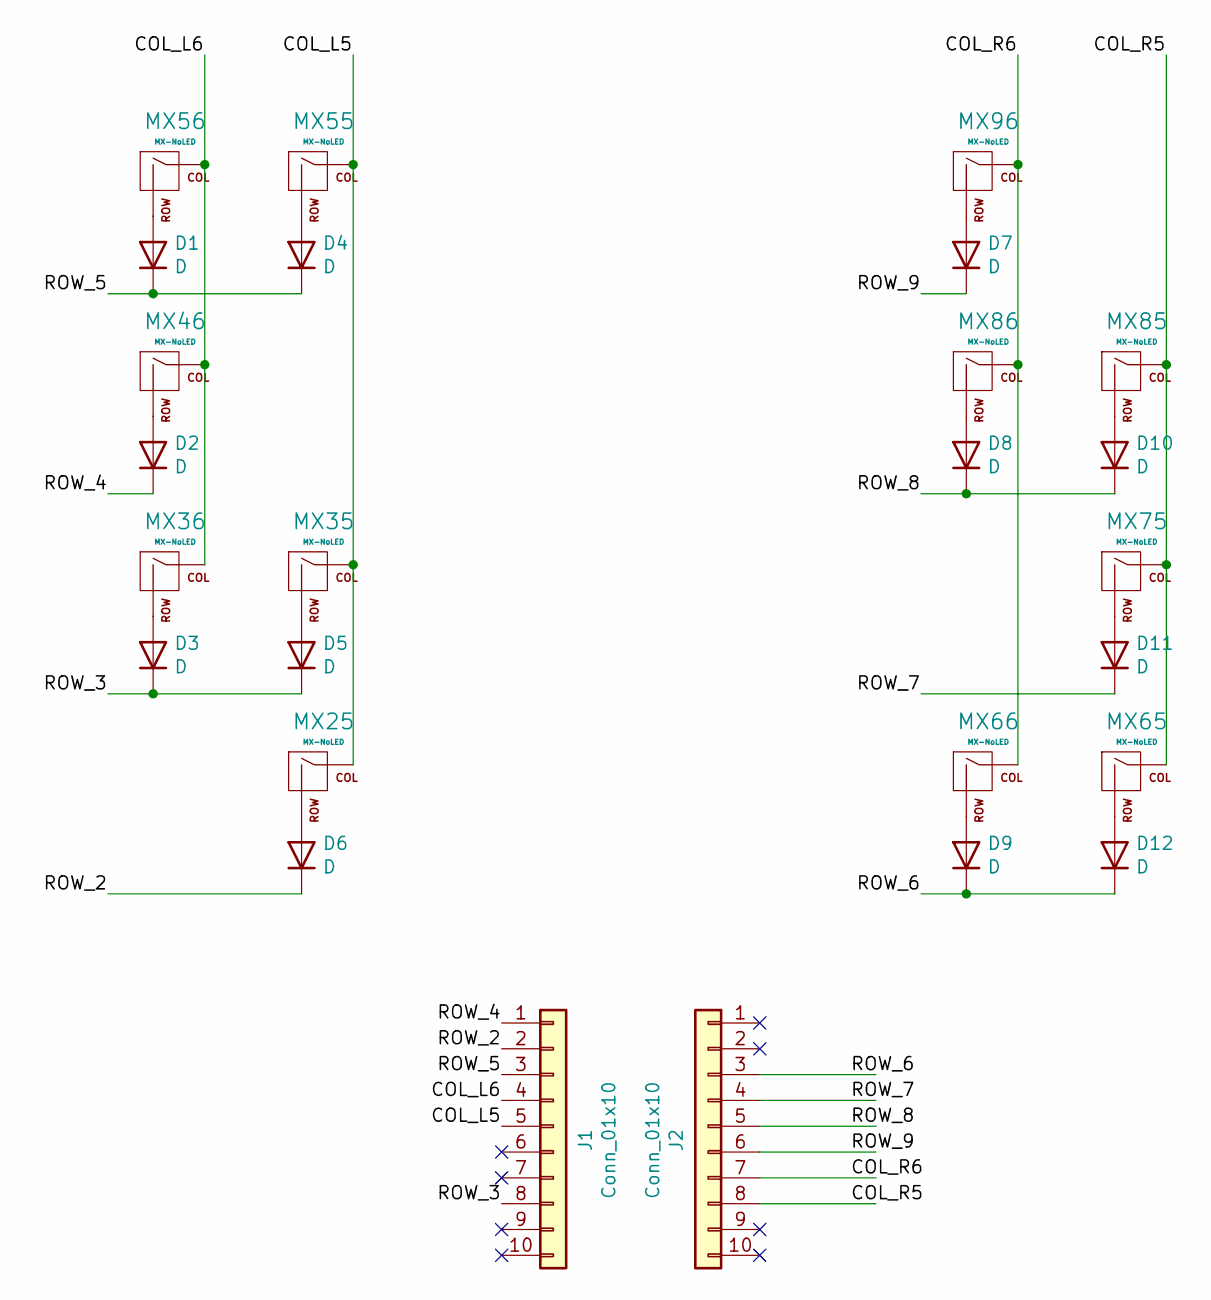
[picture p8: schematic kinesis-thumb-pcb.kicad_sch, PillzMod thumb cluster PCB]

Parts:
D1, D2, D3, D4, D5, D6, D7, D8, D9, D10, D11, D12: D; D_SOD-323_HandSoldering
J1, J2: Conn_01x10; Pin_Header_Straight_1x10_Pitch2.54mm
MX25, MX35, MX36, MX46, MX55, MX56, MX65, MX66, MX75, MX85, MX86, MX96: MX-NoLED

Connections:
/COL_L5: J1.5, MX25.1 (COL), MX35.1 (COL), MX55.1 (COL)
/COL_L6: J1.4, MX36.1 (COL), MX46.1 (COL), MX56.1 (COL)
/COL_R5: J2.8, MX65.1 (COL), MX75.1 (COL), MX85.1 (COL)
/COL_R6: J2.7, MX66.1 (COL), MX86.1 (COL), MX96.1 (COL)
/ROW_2: D6.1 (K), J1.2
/ROW_3: D3.1 (K), D5.1 (K), J1.8
/ROW_4: D2.1 (K), J1.1
/ROW_5: D1.1 (K), D4.1 (K), J1.3
/ROW_6: D9.1 (K), D12.1 (K), J2.3
/ROW_7: D11.1 (K), J2.4
/ROW_8: D8.1 (K), D10.1 (K), J2.5
/ROW_9: D7.1 (K), J2.6
unnamed: D1.2 (A), MX56.2 (ROW)
unnamed: D2.2 (A), MX46.2 (ROW)
unnamed: D3.2 (A), MX36.2 (ROW)
unnamed: D4.2 (A), MX55.2 (ROW)
unnamed: D5.2 (A), MX35.2 (ROW)
unnamed: D6.2 (A), MX25.2 (ROW)
unnamed: D7.2 (A), MX96.2 (ROW)
unnamed: D8.2 (A), MX86.2 (ROW)
unnamed: D9.2 (A), MX66.2 (ROW)
unnamed: D10.2 (A), MX85.2 (ROW)
unnamed: D11.2 (A), MX75.2 (ROW)
unnamed: D12.2 (A), MX65.2 (ROW)

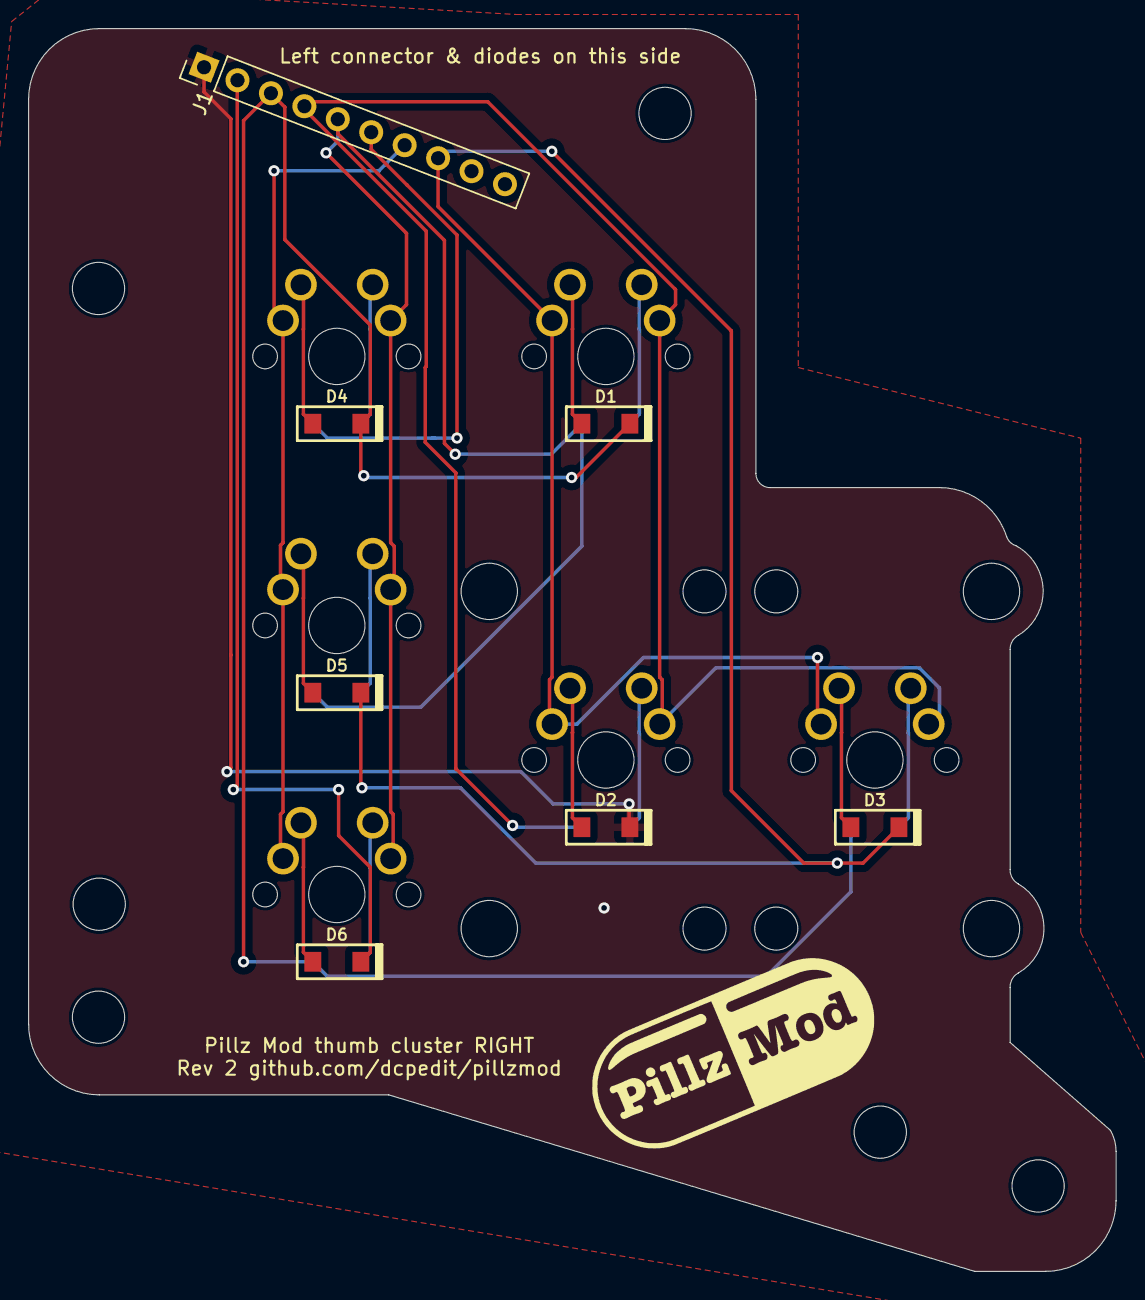
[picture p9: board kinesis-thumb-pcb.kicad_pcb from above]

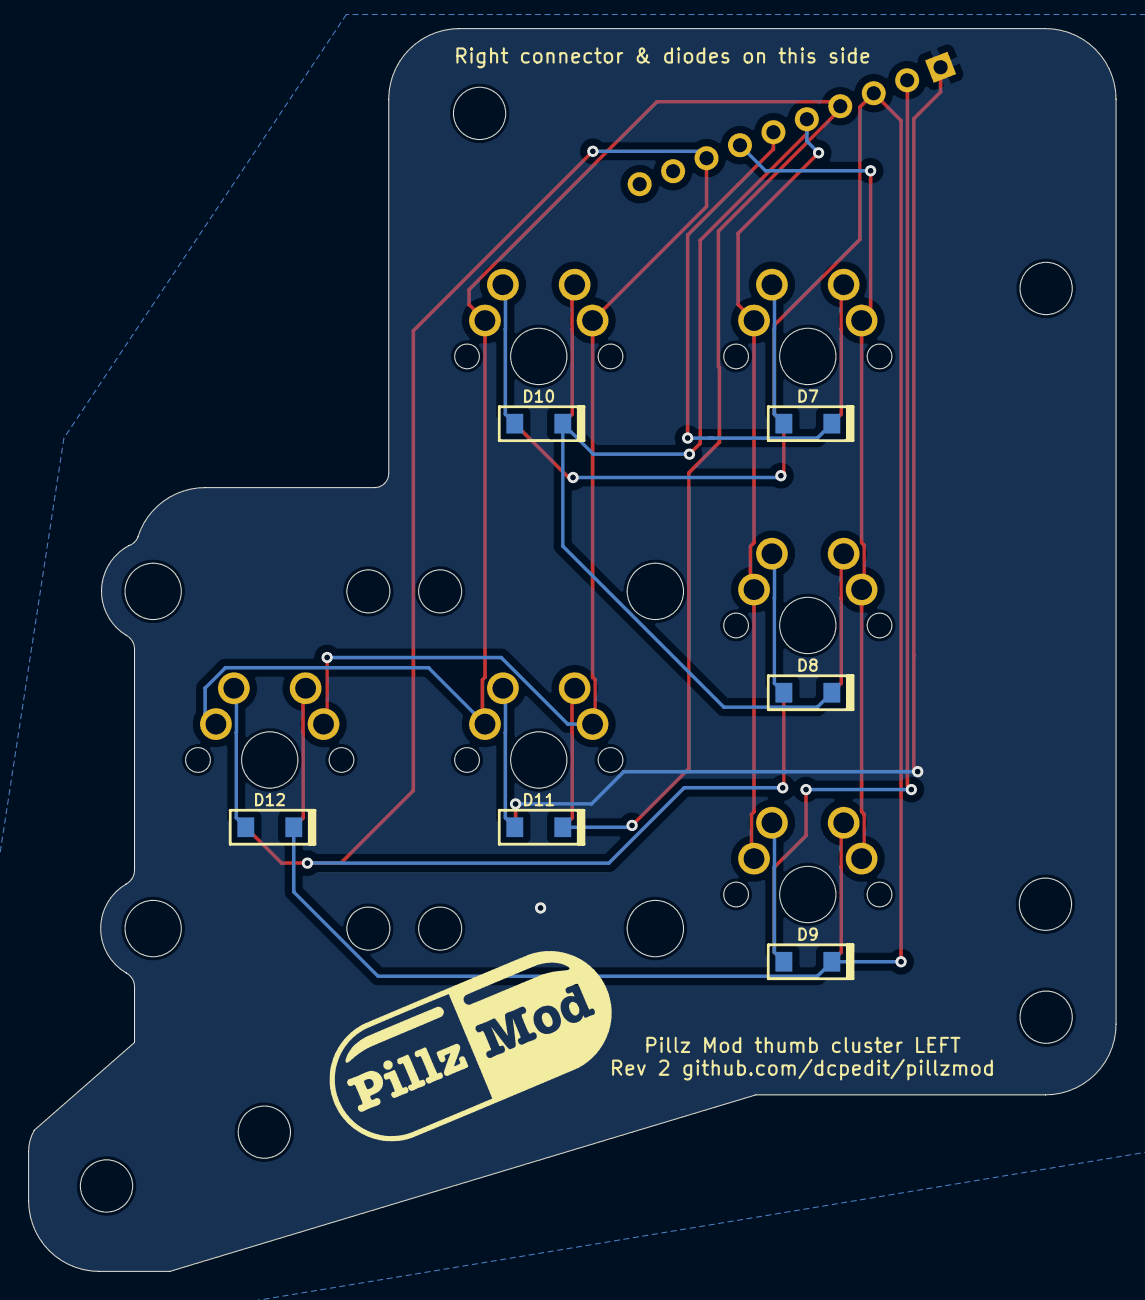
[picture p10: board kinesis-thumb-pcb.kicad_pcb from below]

Board: 2 copper layers, 77.0 x 88.0 mm, 31 parts (18 on the bottom side), 22 nets.

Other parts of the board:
REF1, REF2, REF3, REF4, REF5, REF6: MountingHole_3.7mm

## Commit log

2024-04-12 Update files and readme
    [kinesis-thumb-pcb.kicad_pcb, kinesis-thumb-pcb.kicad_sch]
2024-04-12 Fix BOM links
2024-04-13 Fix bom qty
2024-04-13 Remove old gerbers
2024-04-16 Add readme to pcbs
2024-10-09 pro-micro support
    [kicad_port.kicad_pcb, kicad_port.kicad_sch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]
2024-11-07 Update readme with pro
    [pcb-pro.kicad_pcb, pcb-pro.kicad_sch]
2024-11-14 Tighten up layout
2025-02-19 Update README.MD
    Change link to SW1 component for Pro PCB.
2025-02-22 Add key mapping to README.md
    Makes it easy to track down connector as we as row/cols when debugging.
